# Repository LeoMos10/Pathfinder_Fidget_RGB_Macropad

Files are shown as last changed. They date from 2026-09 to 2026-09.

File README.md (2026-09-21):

# Pathfinder\_Fidget\_RGB\_Macropad

A custom 4-key RGB fidget game / macropad /carrier board for seed studio XIAO
[Prices screenshot](https://github.com/LeoMos10/Pathfinder_Fidget_RGB_Macropad/tree/main/ASSETS/prices)

[docs](DOCS.md)

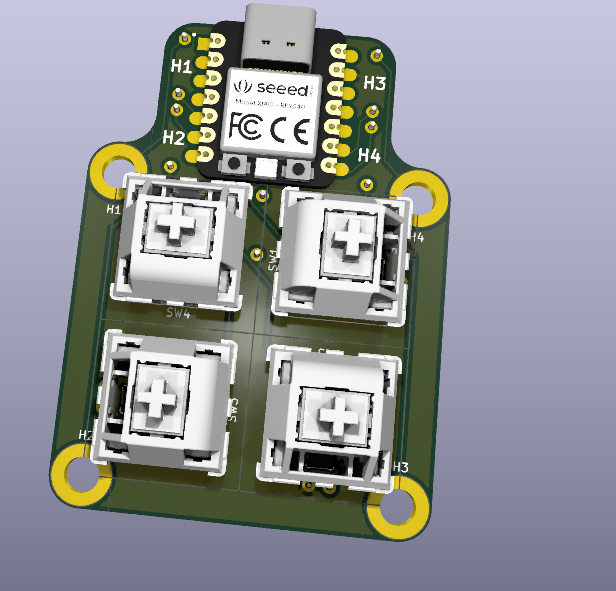
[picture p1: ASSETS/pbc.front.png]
pbc

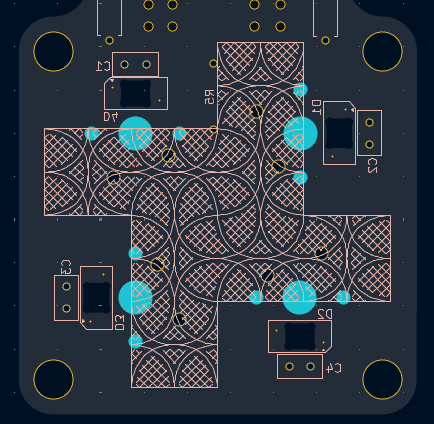
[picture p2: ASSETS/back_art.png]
art


## Parts: (all THT for easier assembly exept led)

* 4x Cherry MX style switches + keycaps(transparent for better effect)
* 4x SK6812MINI-E addressable RGB LEDs, one per each key
* Seeed Studio XIAO RP2040 microcontroller, mounted flat on the front of the board
* 2 layer PCB,  46mm x 63mm
* 2  JP pin header (optional for expanding the board)(2,5mm)
* 2 JP pin header (optiona for easier mounting the XIAO)(2,5mm)
* 4 ceramic condensator 100nF
* 5 resistors (1 × 330 Ω + 4 × 1 kΩ only if using mount holes as GPIO)
*  4x M4 screws (only if using mount hole as indeed)

###  PCB

The pbc was made in KiCad.

board:  46mm x 63mm

[interactive HTML mount guide (made with a KiCad extension)](production/ibom.html)

### Schematic

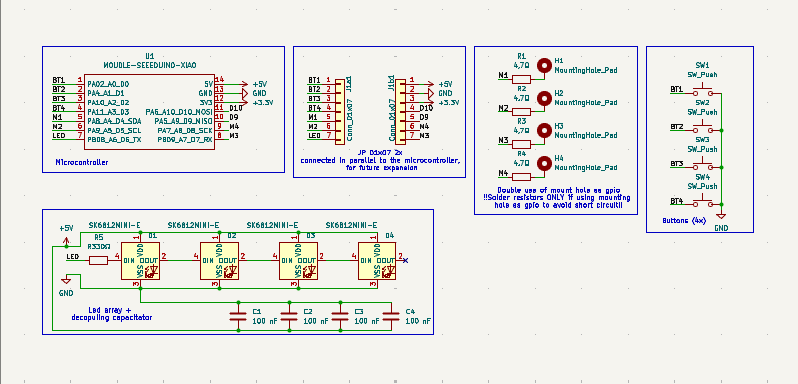
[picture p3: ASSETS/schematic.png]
Schematic


### PCB

Front copper and back copper in the editor (red is F.Cu, blue is B.Cu):

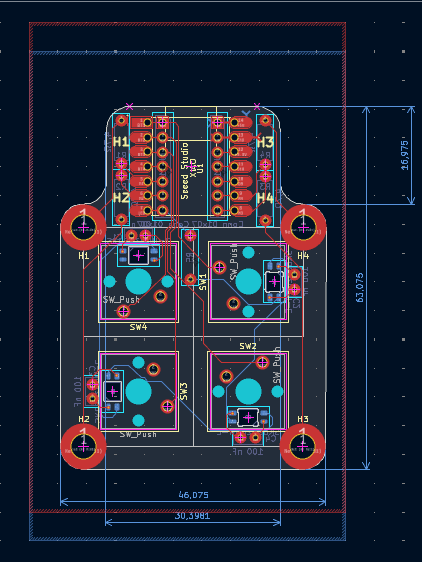
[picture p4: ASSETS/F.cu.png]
PCB front copper


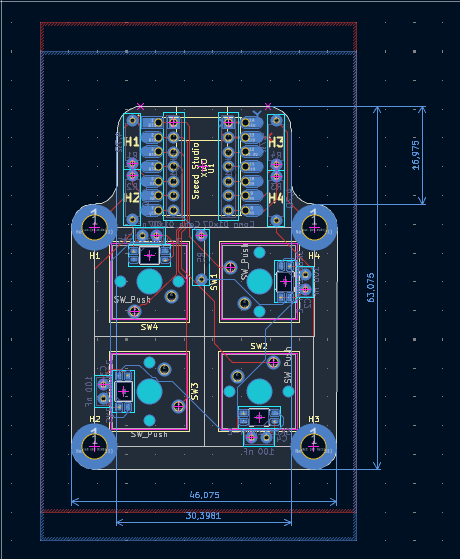
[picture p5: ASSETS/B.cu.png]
PCB back copper


3D renders of the board:

3D render of the front of the board

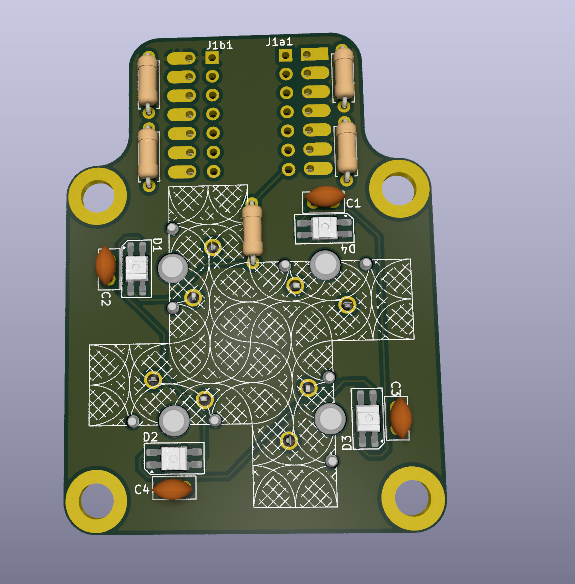
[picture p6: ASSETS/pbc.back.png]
3D render of the back of the board


## Firmware
[DOCS](DOCS.md)

## BOM
[CSV BOM with prices and links](production/bom.csv)
[Prices screenshot](https://github.com/LeoMos10/Pathfinder_Fidget_RGB_Macropad/tree/main/ASSETS/prices)

| Quantity | Name | Component| Footprint | Notes | 
| :-: | :--- | :--- | :--- | :--- |
| 1 | U1 | Seeed Studio XIAO RP2040 | Modulo XIAO RP2040, 14 pin, passo 2.54 mm | Microcontrolloer| [seeedstudio.com](https://www.seeedstudio.com/XIAO-RP2040-p-5058.html) |
| 2 | J1a1, J1b1 | Pin header male 1×7 |  2.54 mm, vertical, THT | Optional| — |
| 4 | SW1–SW4 | Switch Cherry MX compatibile | PCB-mount, 5 pin, 1u | Switch| — |
| 4 | D1–D4 | SK6812MINI-E | RGB addressable, reverse-mount, 3.2 × 2.8 mm | LED RGB| — |
| 4 | C1–C4 | cermaic condesator 100 nF | THT, passo 2.50 mm, diametro 5 mm | Decopuling for led| — |
| 4 | R1–R4 | 1 kΩ resistor | 7.62 mm | Only if using mount holes as GPIO | — |
| 1 | R5 | Resistence 330 Ω | 7.62 mm | In serie sulla linea DIN dei LED | — |
| 4 | H1–H4 | screw M4 | 4.3 mm | Only if using mount holes as indeed | — |

- USE `SK6812MINI-E` reverse-mount, NOT `SK6812MINI`

total price:
with shipping and taxes:

## AI usage

AI was never used for:

* schematic design
* PCB design

*instead, it was used a little for:
*firmware and code

the drc rule
HARDWARE/kicad/path_finder.kicad_dru
## Extra stuff

easily soldable, perfect for beginners in soldering and coding

The contributors is both me

see [docs](DOCS.md)

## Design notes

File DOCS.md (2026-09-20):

Other than the JP for al the pins on the borard here is the pinout:

|- |left | right
|- | - |-|
top     |Button4-D3 + led1 + Hole1-D4   |Button1- D0 + led1 + Hole4-D8|
bototm  |Button3-D2 + led1 + Hole2-D5   |Button2-D1 + led1 + Hole3-D7|
Led chain D6

To activate a hole as GPIO, solder its 1 kΩ resistor (H1 uses R1, etc.). Do not populate these resistors when the holes are used as mounting holes.

## Pinout:
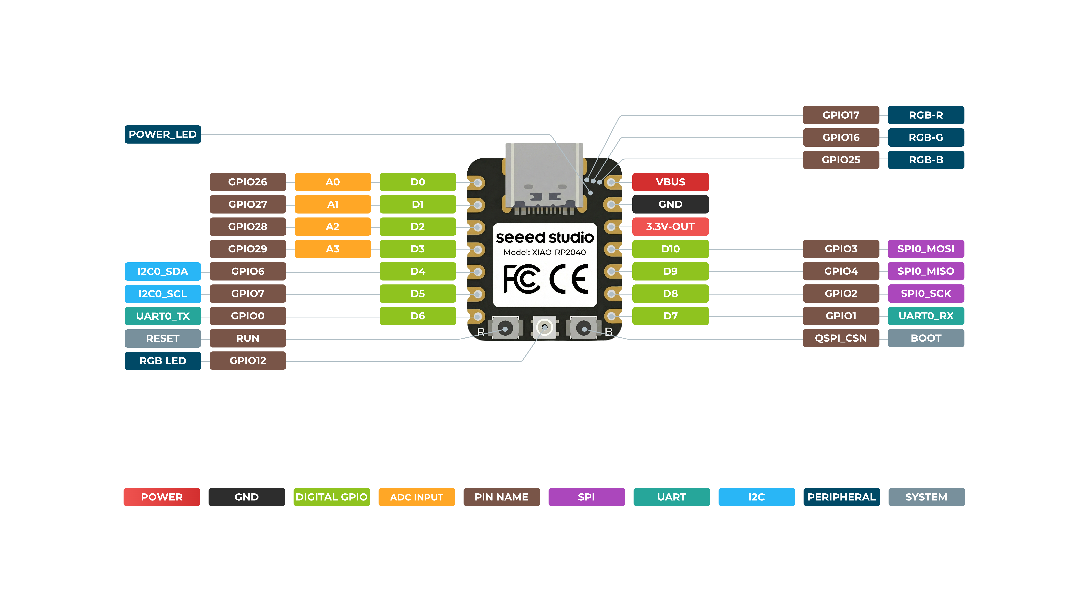
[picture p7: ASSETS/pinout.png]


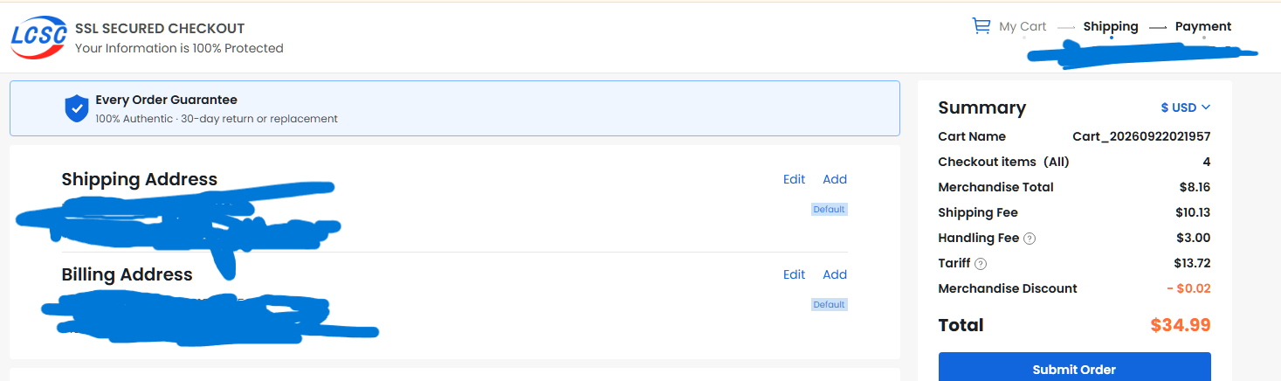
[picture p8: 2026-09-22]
ASSETS/prices/Screenshot 2026-09-22 170425.png

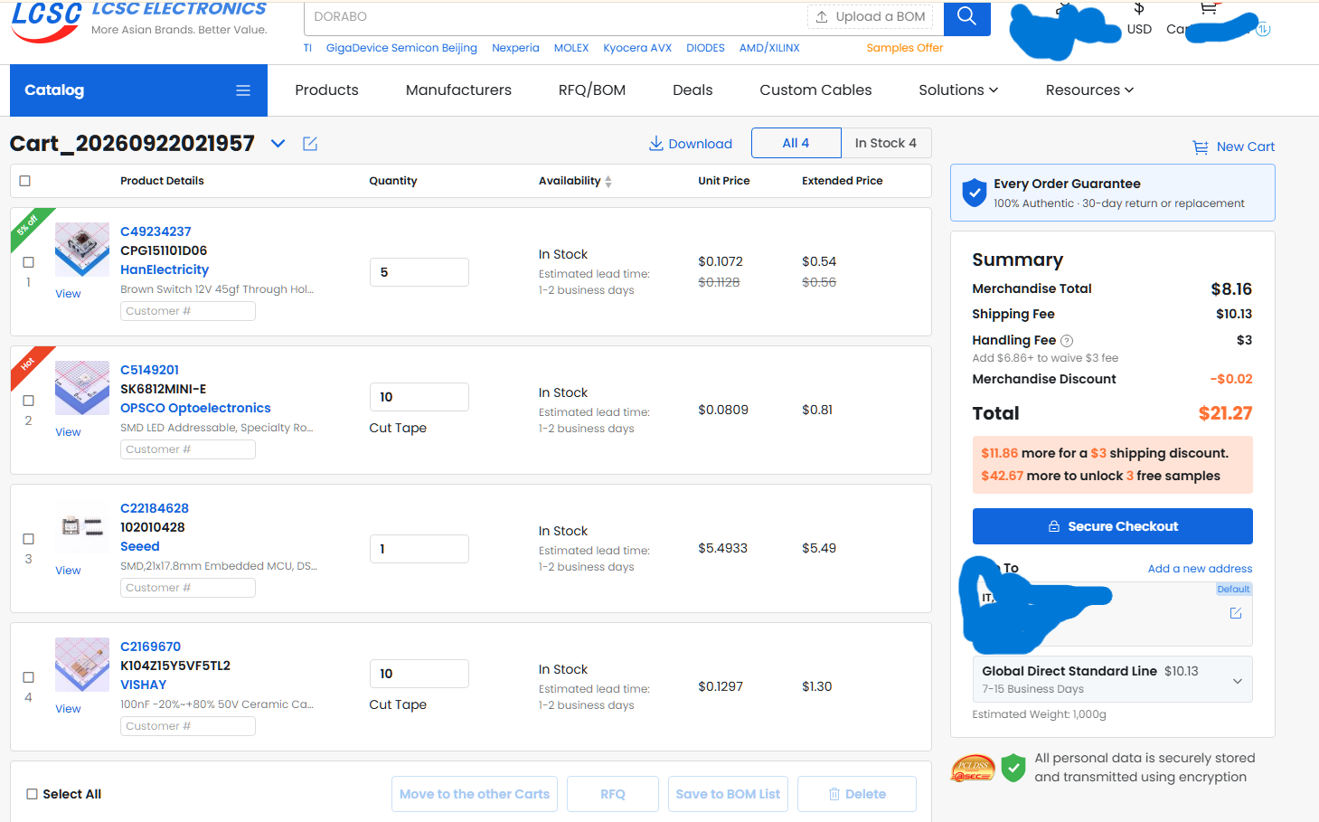
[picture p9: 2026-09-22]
ASSETS/prices/Screenshot 2026-09-22 170434.png

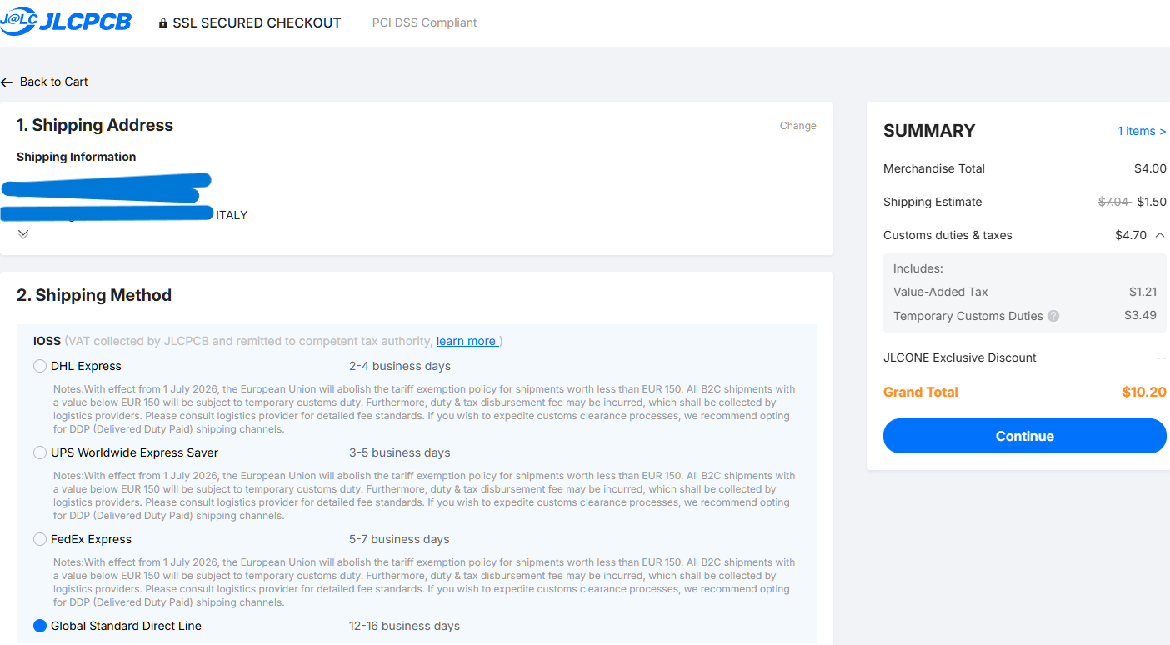
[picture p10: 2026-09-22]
ASSETS/prices/Screenshot 2026-09-22 172233.png

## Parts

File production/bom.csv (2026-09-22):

Designators | Qty Required | Item | Specification / Footprint | Status | LCSC Product | Final Price
U1 | 1 | Seeed Studio XIAO RP2040 | 102010428; XIAO-Generic-Hybrid-14P-2.54-21X17.8MM | In LCSC cart | https://www.lcsc.com/product-detail/C22184628.html
SW1-SW4 | 4 | Cherry MX-compatible mechanical switch | CPG151101D06; SW_Cherry_MX_1.00u_PCB | 5 in LCSC cart; verify 5-pin MX fit before checkout | https://www.lcsc.com/product-detail/C49234237.html
D1-D4 | 4 | Addressable RGB LED | SK6812MINI-E reverse-mount; LED_SK6812MINI-E_3.2x2.8mm_P1.5mm_ReverseMount | 10 in LCSC cart | https://www.lcsc.com/product-detail/C5149201.html
C1-C4 | 4 | 100 nF THT ceramic capacitor | K104Z15Y5VF5TL2; C_Disc_D5.0mm_W2.5mm_P2.50mm | 10 in LCSC cart | https://www.lcsc.com/product-detail/C2169670.html
R1-R4 | 4 | 1 kOhm THT resistor | 7.62 mm axial footprint | Optional; populate only if H1-H4 are used as GPIO | https://www.lcsc.com/product-detail/C57435.html
R5 | 1 | 330 Ohm THT resistor | 7.62 mm axial footprint | Required; not in the shown LCSC cart | https://www.lcsc.com/product-detail/C119313.html
J1A1-J1B1 | 2 | 1x7 male pin header | 2.54 mm vertical THT | Optional; cut two 1x7 headers from a 1x40 strip | https://www.lcsc.com/product-detail/C2337.html
H1-H4 | 4 | M4 screws and standoffs | 4.3 mm mounting holes | Optional; required only when the holes are used for mounting
KEY1-KEY4 | 4 | 1U MX-compatible keycap | MX cross stem | Required for a finished macropad; buy outside LCSC
Parts |  |  |  | LCSC checkout shown on 2026-09-22; excludes items not in the cart |  | $34.99 USD
PCB |  |  |  | JLCPCB checkout shown on 2026-09-22 |  | $10.20 USD
Total |  |  |  | Parts plus PCB |  | ${45.19} USD

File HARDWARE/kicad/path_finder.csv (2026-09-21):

Reference | Qty | Value | DNP | Exclude from BOM | Exclude from Board | Exclude from Simulation | Exclude from Position Files | Footprint | Datasheet
C1,C2,C3,C4 | 4 | 100 nF |  |  |  |  | ${EXCLUDE_FROM_POS_FILES} | Capacitor_THT:C_Disc_D5.0mm_W2.5mm_P2.50mm
D1,D2,D3,D4 | 4 | SK6812MINI-E |  |  |  |  | ${EXCLUDE_FROM_POS_FILES} | LED_SMD:LED_SK6812MINI-E_3.2x2.8mm_P1.5mm_ReverseMount | https://cdn-shop.adafruit.com/product-files/4960/4960_SK6812MINI-E_REV02_EN.pdf
J1a1,J1b1 | 2 | Conn_01x07 |  |  |  |  | ${EXCLUDE_FROM_POS_FILES} | Connector_PinHeader_2.54mm:PinHeader_1x07_P2.54mm_Vertical
R1,R2,R3,R4 | 4 | 1 kΩ |  |  |  |  | ${EXCLUDE_FROM_POS_FILES} | Resistor_THT:R_Axial_DIN0207_L6.3mm_D2.5mm_P7.62mm_Horizontal
R5 | 1 | R330Ω |  |  |  |  | ${EXCLUDE_FROM_POS_FILES} | Resistor_THT:R_Axial_DIN0207_L6.3mm_D2.5mm_P7.62mm_Horizontal
SW1,SW2,SW3,SW4 | 4 | SW_Push |  |  |  |  | ${EXCLUDE_FROM_POS_FILES} | Button_Switch_Keyboard:SW_Cherry_MX_1.00u_PCB
U1 | 1 | MOUDLE-SEEEDUINO-XIAO |  |  |  |  | ${EXCLUDE_FROM_POS_FILES} | HackPad:XIAO-Generic-Hybrid-14P-2.54-21X17.8MM

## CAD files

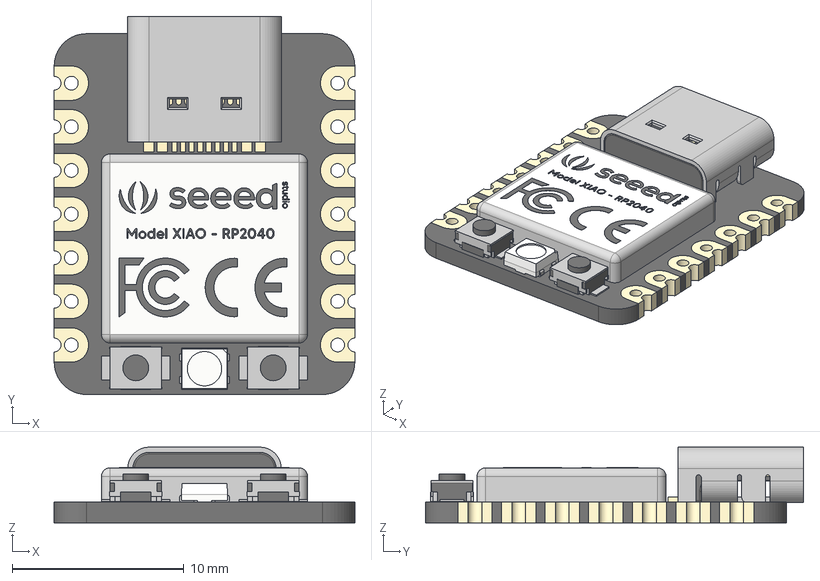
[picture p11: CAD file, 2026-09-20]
HARDWARE/kicad/3dmodels/XIAO_RP2040.step
17.5 x 22.0 x 4.40 mm
type-c v2
smd_button v3
DOUT
DIN
VSS
VDD
smd_button v3(Mirror)

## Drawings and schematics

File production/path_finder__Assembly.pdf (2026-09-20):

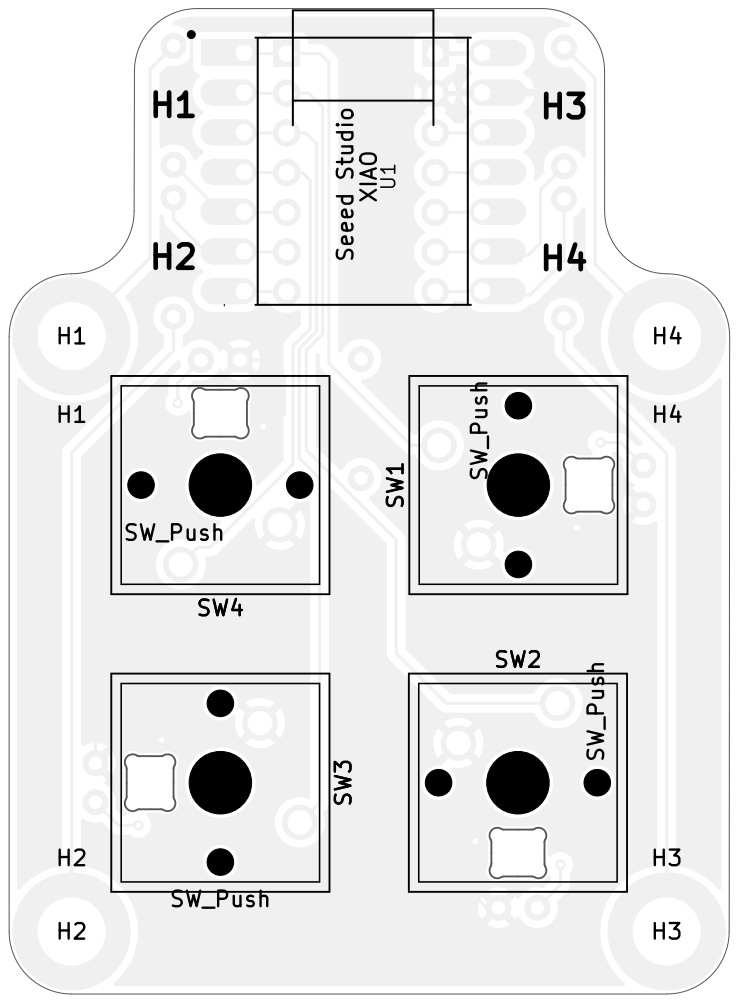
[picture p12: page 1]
SW³; H4 SW¹; D Date:; Size: A4; Rev:; SW_Push; SW_PushSW2; SW_PushSW4; H4 SW_Push SW¹

H3 U1 Seeed Studio XIAO

Board2Pdf: Black And White TOP - Page 1/2

Sheet: Black And White TOP
File: path_finder.kicad_pcb
Title:
KiCad E.D.A. 10.0.5

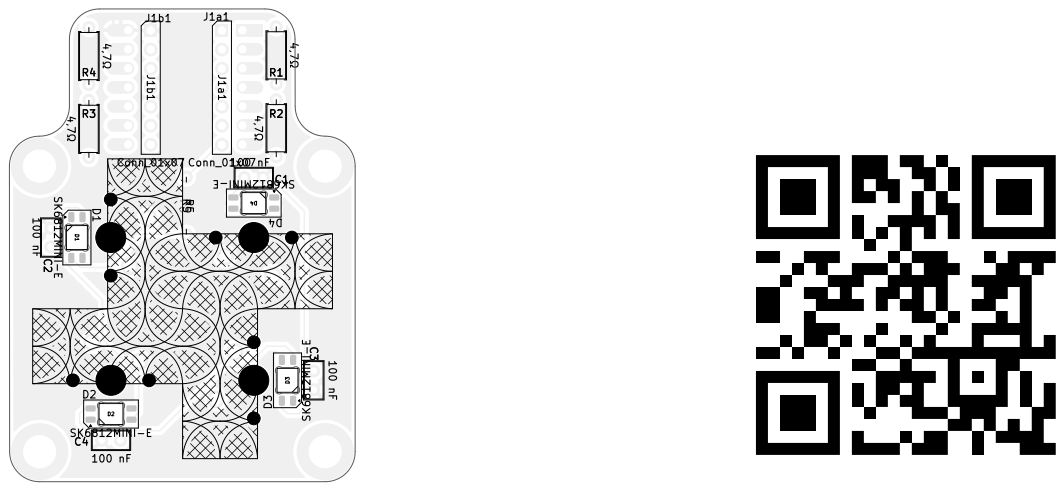
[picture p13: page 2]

Board2Pdf: Black And White BOT - Page 2/2 ⁴,7Ω

Sheet: Black And White BOT
File: path_finder.kicad_pcb
Title:
KiCad E.D.A. 10.0.5

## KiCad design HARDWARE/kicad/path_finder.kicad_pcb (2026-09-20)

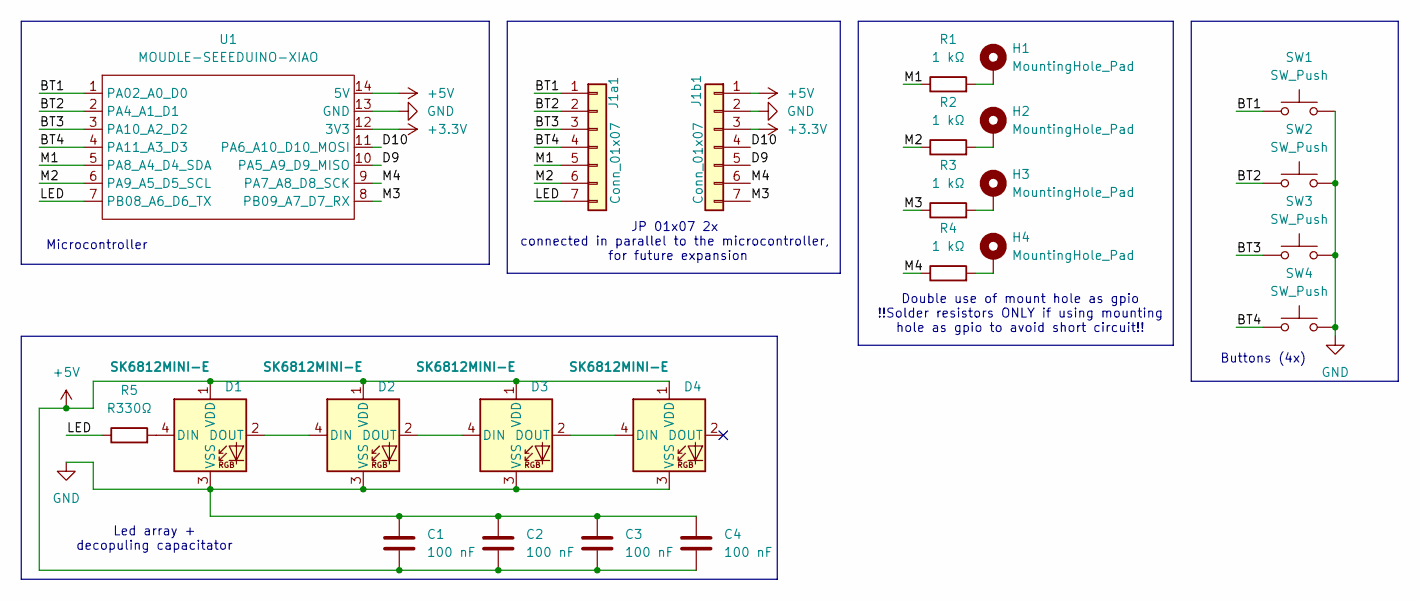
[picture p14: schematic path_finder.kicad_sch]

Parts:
C1, C2, C3, C4: 100 nF; C_Disc_D5.0mm_W2.5mm_P2.50mm
D1, D2, D3, D4: SK6812MINI-E; LED_SK6812MINI-E_3.2x2.8mm_P1.5mm_ReverseMount
H1, H2, H3, H4: MountingHole_Pad; MountingHole_4.3mm_M4_DIN965_Pad_TopBottom
J1a1, J1b1: Conn_01x07; PinHeader_1x07_P2.54mm_Vertical
R1, R2, R3, R4: 1 kΩ; R_Axial_DIN0207_L6.3mm_D2.5mm_P7.62mm_Horizontal
R5: R330Ω; R_Axial_DIN0207_L6.3mm_D2.5mm_P7.62mm_Horizontal
SW1, SW2, SW3, SW4: SW_Push; SW_Cherry_MX_1.00u_PCB
U1: MOUDLE-SEEEDUINO-XIAO; XIAO-Generic-Hybrid-14P-2.54-21X17.8MM

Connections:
+3.3V: J1b1.3, U1.12 (3V3)
+5V: C1.2, C2.2, C3.2, C4.2, D1.1 (VDD), D2.1 (VDD), D3.1 (VDD), D4.1 (VDD), J1b1.1, U1.14 (5V)
/BT1: J1a1.1, SW1.1, U1.1 (PA02_A0_D0)
/BT2: J1a1.2, SW2.1, U1.2 (PA4_A1_D1)
/BT3: J1a1.3, SW3.1, U1.3 (PA10_A2_D2)
/BT4: J1a1.4, SW4.1, U1.4 (PA11_A3_D3)
/D9: J1b1.5, U1.10 (PA5_A9_D9_MISO)
/D10: J1b1.4, U1.11 (PA6_A10_D10_MOSI)
/LED: J1a1.7, R5.1, U1.7 (PB08_A6_D6_TX)
/M1: J1a1.5, R1.1, U1.5 (PA8_A4_D4_SDA)
/M2: J1a1.6, R2.1, U1.6 (PA9_A5_D5_SCL)
/M3: J1b1.7, R3.1, U1.8 (PB09_A7_D7_RX)
/M4: J1b1.6, R4.1, U1.9 (PA7_A8_D8_SCK)
GND: C1.1, C2.1, C3.1, C4.1, D1.3 (VSS), D2.3 (VSS), D3.3 (VSS), D4.3 (VSS), J1b1.2, SW1.2, SW2.2, SW3.2, SW4.2, U1.13 (GND)
unnamed: D1.4 (DIN), R5.2
unnamed: D1.2 (DOUT), D2.4 (DIN)
unnamed: D2.2 (DOUT), D3.4 (DIN)
unnamed: D3.2 (DOUT), D4.4 (DIN)
unnamed: H1.1 (1_1), R1.2
unnamed: H2.1 (1_1), R2.2
unnamed: H3.1 (1_1), R3.2
unnamed: H4.1 (1_1), R4.2

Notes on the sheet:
Buttons (4x)
JP 01x07 2x connected in parallel to the microcontroller, for future expansion
Double use of mount hole as gpio !!Solder resistors ONLY if using mounting hole as gpio to avoid short circuit!!
Microcontroller
Led array + decopuling capacitator

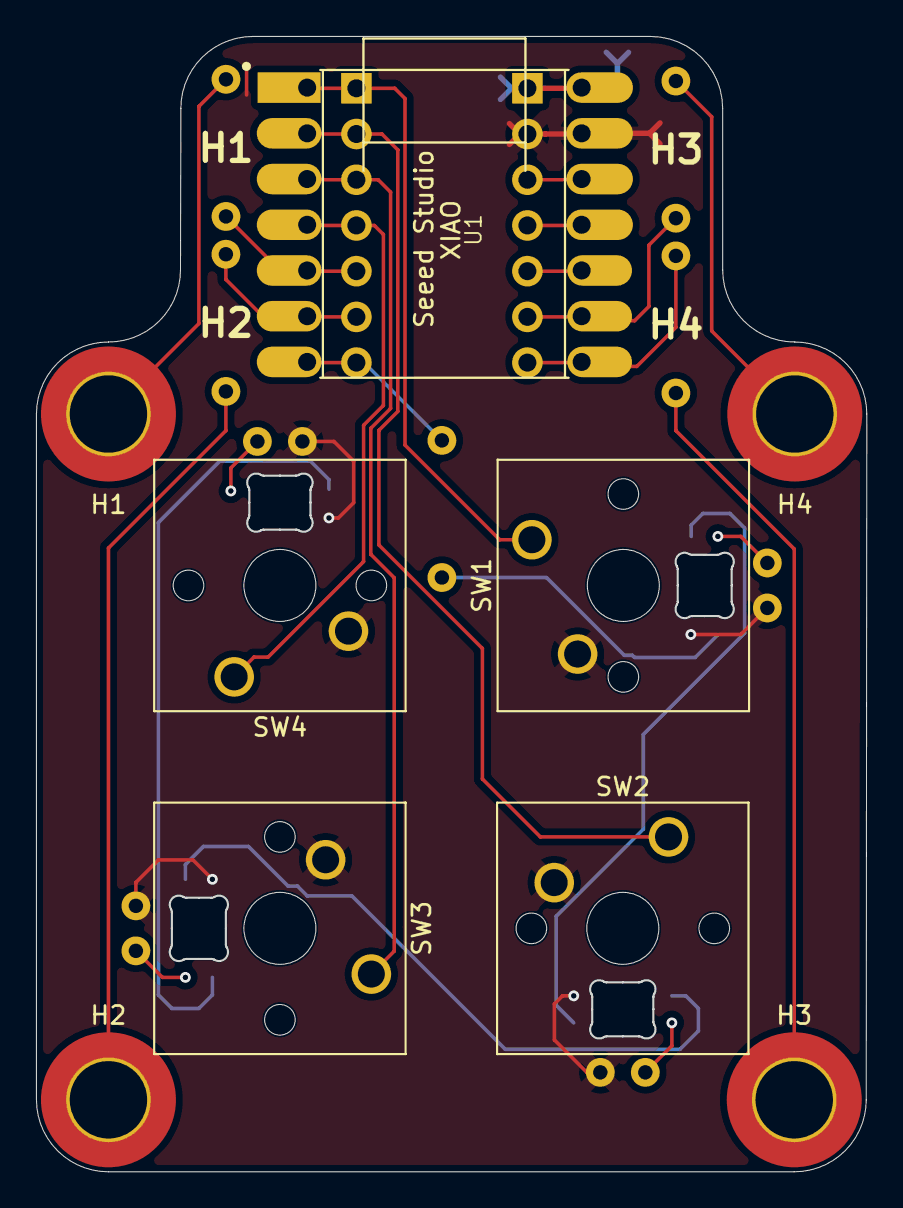
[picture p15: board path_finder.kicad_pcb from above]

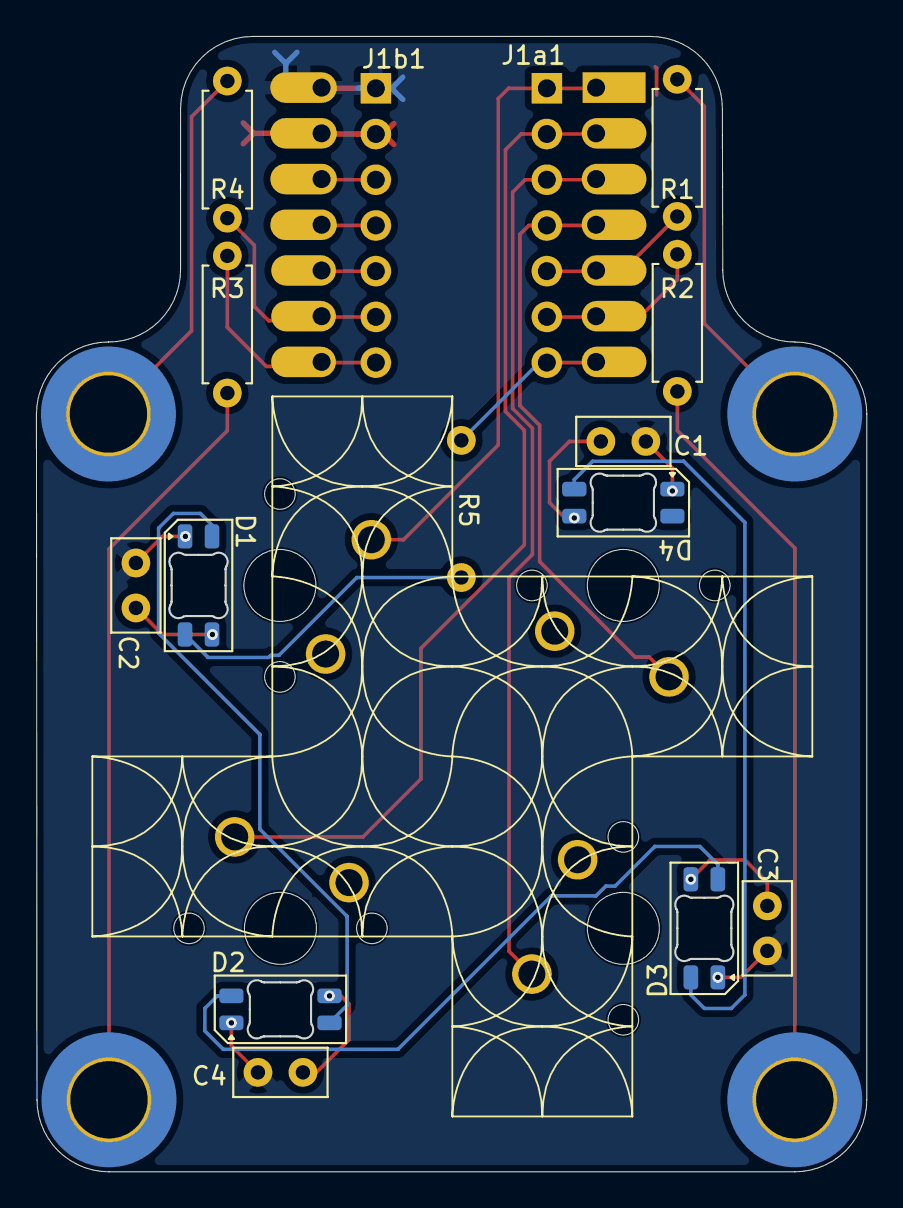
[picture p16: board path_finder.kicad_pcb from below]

Board: 2 copper layers, 46.1 x 63.1 mm, 24 parts (15 on the bottom side), 22 nets.

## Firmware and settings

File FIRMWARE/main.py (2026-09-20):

# Pathfinder reaction test - MicroPython
#
# Button order on the PCB:
#   0 = top-left     = D3 = GPIO29
#   1 = top-right    = D0 = GPIO26
#   2 = bottom-left  = D2 = GPIO28
#   3 = bottom-right = D1 = GPIO27
#
# XIAO RP2040 onboard RGB LED (active-low):
#   red = GPIO17, green = GPIO16, blue = GPIO25

from machine import Pin
import time
import urandom


# ---------- Hardware and game settings ----------

BUTTON_GPIOS = (29, 26, 28, 27)

XIAO_LED_R_GPIO = 17
XIAO_LED_G_GPIO = 16
XIAO_LED_B_GPIO = 25

DEBOUNCE_MS = 25
MIN_WAIT_MS = 1500
MAX_WAIT_MS = 10000
REACTION_TIMEOUT_MS = 2000
MAX_SCORES = 10


# ---------- Hardware initialisation ----------

# A pressed switch connects its GPIO to GND.
buttons = [Pin(gpio, Pin.IN, Pin.PULL_UP) for gpio in BUTTON_GPIOS]

# The onboard RGB LED is active-low: value 0 turns a colour on.
led_r = Pin(XIAO_LED_R_GPIO, Pin.OUT, value=1)
led_g = Pin(XIAO_LED_G_GPIO, Pin.OUT, value=1)
led_b = Pin(XIAO_LED_B_GPIO, Pin.OUT, value=1)

# Stores the latest valid reaction times in milliseconds.
scores = []


# ---------- LED helpers ----------

def set_xiao_rgb(red=False, green=False, blue=False):
    """Set the XIAO onboard RGB status LED."""
    led_r.value(0 if red else 1)
    led_g.value(0 if green else 1)
    led_b.value(0 if blue else 1)


def show_average(average_ms):
    """Show the rolling average: green <=250 ms, yellow <=400 ms, red otherwise."""
    if average_ms <= 250:
        set_xiao_rgb(False, True, False)
    elif average_ms <= 400:
        set_xiao_rgb(True, True, False)
    else:
        set_xiao_rgb(True, False, False)


# ---------- Button helpers ----------

def pressed_button():
    """Return the pressed button index (0..3), or -1 when no button is pressed."""
    for index, button in enumerate(buttons):
        if button.value() == 0:
            return index
    return -1


def wait_all_released():
    """Wait until all buttons have stayed released for DEBOUNCE_MS."""
    released_since = time.ticks_ms()

    while True:
        if pressed_button() == -1:
            if time.ticks_diff(time.ticks_ms(), released_since) >= DEBOUNCE_MS:
                return
        else:
            released_since = time.ticks_ms()

        time.sleep_ms(2)


def wait_for_press(timeout_ms):
    """Return (button_index, press_time_ms), or (-1, None) after timeout_ms."""
    start = time.ticks_ms()
    candidate = -1
    candidate_since = start

    while time.ticks_diff(time.ticks_ms(), start) < timeout_ms:
        current = pressed_button()
        now = time.ticks_ms()

        if current != candidate:
            candidate = current
            candidate_since = now

        if candidate != -1 and time.ticks_diff(now, candidate_since) >= DEBOUNCE_MS:
            # candidate_since is the first sampled instant of the press, so it
            # does not include the time the player keeps the key held down.
            return candidate, candidate_since

        time.sleep_ms(2)

    return -1, None


# ---------- Reaction game ----------

def random_wait_ms():
    """Generate a random delay from MIN_WAIT_MS to MAX_WAIT_MS."""
    span = MAX_WAIT_MS - MIN_WAIT_MS + 1
    return MIN_WAIT_MS + (urandom.getrandbits(16) % span)


def add_score(reaction_ms):
    """Store a valid reaction time and retain only the most recent MAX_SCORES."""
    scores.append(reaction_ms)
    if len(scores) > MAX_SCORES:
        scores.pop(0)


def average_score():
    """Return the average valid reaction time in milliseconds."""
    return sum(scores) // len(scores)


def play_round():
    """
    Orange: wait without pressing.
    White: GO, press any of the four buttons as quickly as possible.
    Red: pressed too early.
    Blue: timed out.
    Green/yellow/red after a valid press: rolling-average category.
    """
    wait_all_released()

    # Orange means that the random waiting phase has started.
    set_xiao_rgb(True, True, False)
    early_button, _ = wait_for_press(random_wait_ms())

    if early_button != -1:
        set_xiao_rgb(True, False, False)
        print("Too early - round cancelled")
        time.sleep_ms(1000)
        return

    # White is the GO signal. Any button is valid in this reaction test.
    set_xiao_rgb(True, True, True)
    start = time.ticks_ms()
    button, press_time = wait_for_press(REACTION_TIMEOUT_MS)

    if button == -1:
        set_xiao_rgb(False, False, True)
        print("Timed out")
        time.sleep_ms(1000)
        return

    reaction_ms = time.ticks_diff(press_time, start)
    add_score(reaction_ms)
    average_ms = average_score()

    print("Button %d | %d ms | average of %d: %d ms" % (
        button + 1, reaction_ms, len(scores), average_ms
    ))

    show_average(average_ms)
    time.sleep_ms(1500)


def boot_animation():
    """Check red, green and blue channels when the board starts."""
    for colour in ((True, False, False), (False, True, False), (False, False, True)):
        set_xiao_rgb(*colour)
        time.sleep_ms(180)
    set_xiao_rgb(False, False, True)


def main():
    boot_animation()
    wait_all_released()
    print("Reaction test ready: orange = wait, white = press any button")

    while True:
        play_round()
        time.sleep_ms(300)


main()

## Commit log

2026-09-20 now i really commited last was a joke
    [XIAO_RP2040.step, path_finder.kicad_pcb, path_finder.kicad_sch]
2026-09-21 update bom and .gitignore to not ignore bom
2026-09-21 added bom in xlsx format
    [bom.xlsx, path_finder.csv]
2026-09-21 Update BOM link from CSV to XLSX format
2026-09-21 fixed csv bom
    [bom.csv]
2026-09-22 changed part soruce to lcsc
    [bom.csv]
